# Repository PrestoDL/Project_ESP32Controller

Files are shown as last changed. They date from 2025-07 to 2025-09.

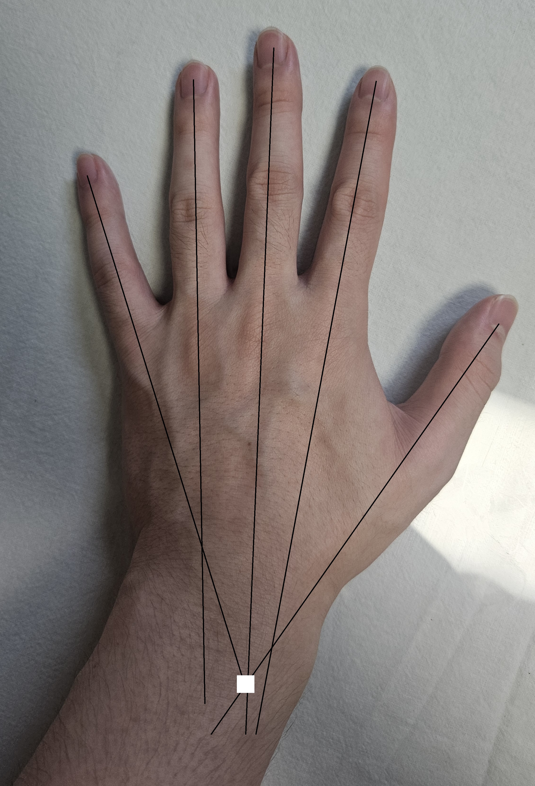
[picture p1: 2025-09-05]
modeling/hand.jpg

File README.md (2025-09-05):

# Project_ESP32Controller
Project about ESP32 motion controller with ESP-IDF. For IoT properties, additional function will be installed.

Demo test is about controlling light with http request by simple motion.

Demo test in my channel :

https://youtube.com/shorts/M0vYTvH4euw?si=jk3dXooK5vRalX_q

KakaoTalk_20250905_214945616

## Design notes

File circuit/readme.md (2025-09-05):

PCB circuit design on KiCad.

circuitSCH

circuitPCB

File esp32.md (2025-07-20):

# FreeRTOS

## // Task

메인 루프의 일종이라고 보면 될 것

## // Wi-Fi

대표적으로 두가지 모드가 있다

액세스 포인트(AP) : 다른 장치들이 연결할 수 있는, 일종의 공유기로 보드를 사용

스테이션(STA) : 보드를 다른 네트워크에 연결하여 인터넷 액세스 등 가능

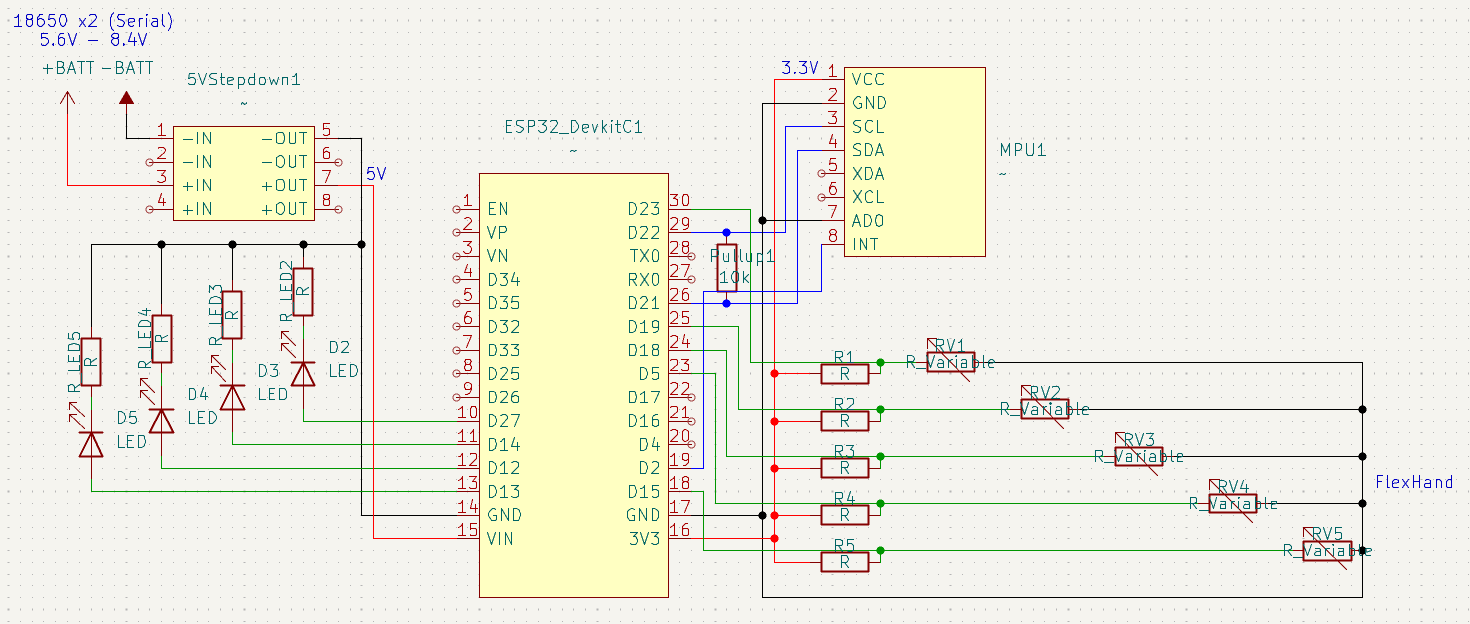
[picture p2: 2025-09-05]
circuit/circuitSCH.png

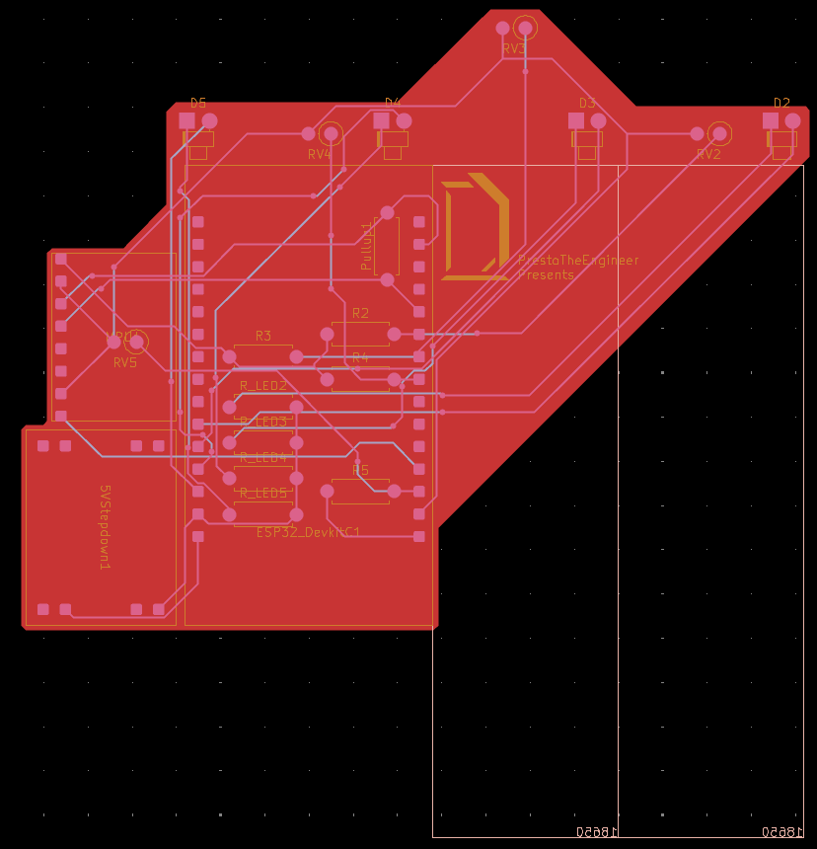
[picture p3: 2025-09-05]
circuit/circuitPCB.png

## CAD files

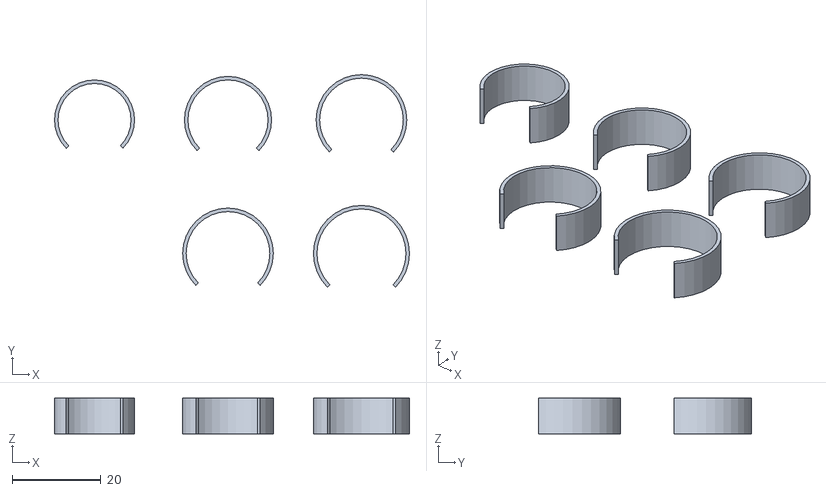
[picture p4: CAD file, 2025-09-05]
modeling/fingTemp.stl
79.8 x 47.8 x 8.00

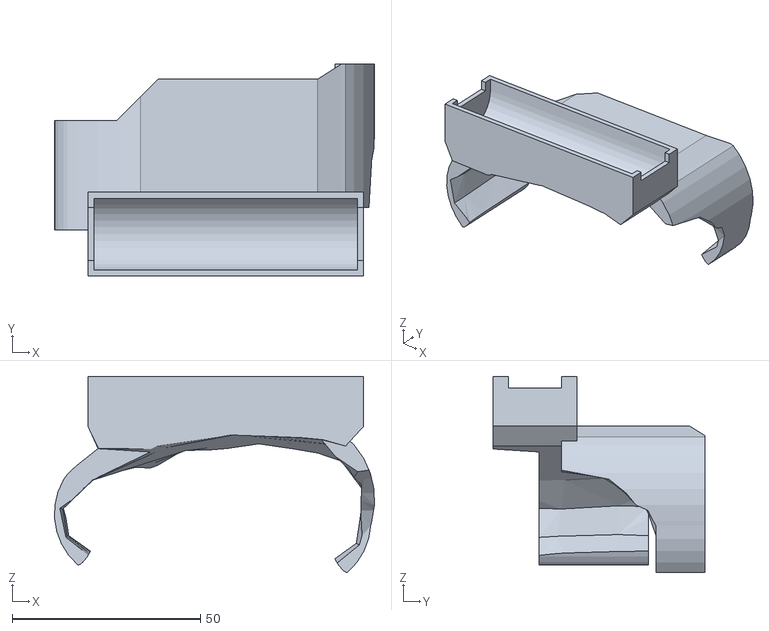
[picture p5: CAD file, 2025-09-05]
modeling/wristTemp.stl
84.9 x 56.2 x 52.0

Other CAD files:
modeling/WristController.blend

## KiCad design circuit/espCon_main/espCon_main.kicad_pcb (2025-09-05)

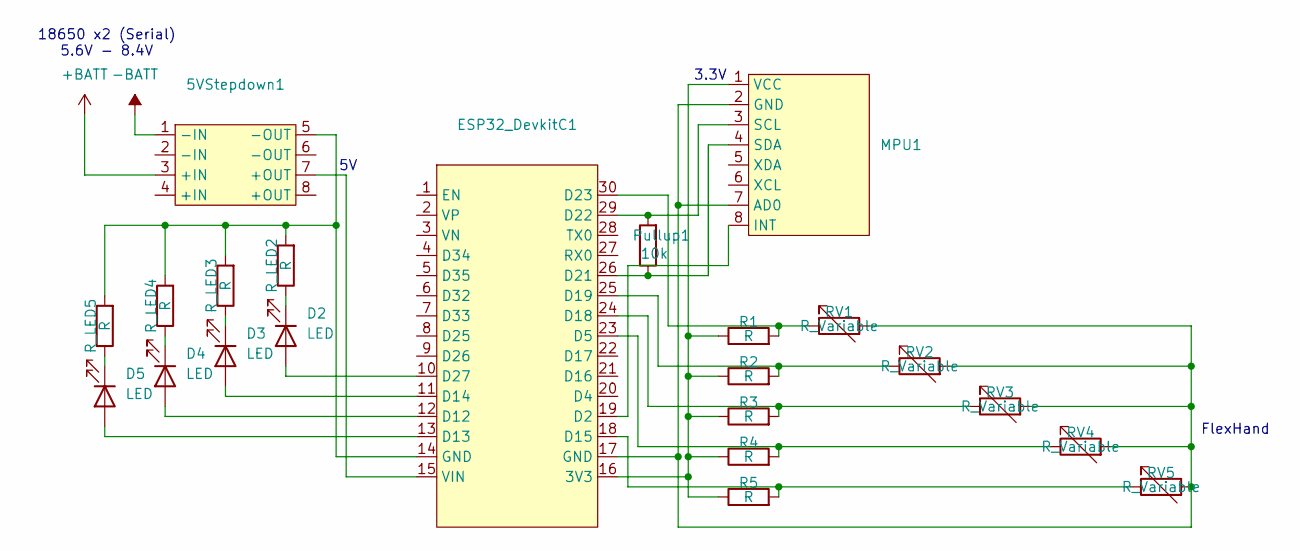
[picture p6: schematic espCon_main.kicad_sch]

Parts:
5VStepdown1: 5VStepdown
D2, D3, D4, D5: LED; LED_D1.8mm_W1.8mm_H2.4mm_Horizontal_O1.27mm_Z1.6mm
ESP32_DevkitC1: ESP32_DevkitC
MPU1: GY-521
Pullup1: 10k; R_Axial_DIN0207_L6.3mm_D2.5mm_P2.54mm_Vertical
R1, R2, R3, R4, R5: R; R_Axial_DIN0207_L6.3mm_D2.5mm_P2.54mm_Vertical
RV1, RV2, RV3, RV4, RV5: R_Variable; R_Axial_DIN0207_L6.3mm_D2.5mm_P2.54mm_Vertical
R_LED2, R_LED3, R_LED4, R_LED5: R; R_Axial_DIN0207_L6.3mm_D2.5mm_P2.54mm_Vertical

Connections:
+BATT: 5VStepdown1.3 (+IN)
-BATT: 5VStepdown1.1 (-IN)
unnamed: 5VStepdown1.5 (-OUT), ESP32_DevkitC1.14 (GND), R_LED2.2, R_LED3.2, R_LED4.2, R_LED5.2
unnamed: D2.2 (A), ESP32_DevkitC1.10 (D27)
unnamed: D2.1 (K), R_LED2.1
unnamed: D3.2 (A), ESP32_DevkitC1.11 (D14)
unnamed: D3.1 (K), R_LED3.1
unnamed: D4.2 (A), ESP32_DevkitC1.12 (D12)
unnamed: D4.1 (K), R_LED4.1
unnamed: D5.2 (A), ESP32_DevkitC1.13 (D13)
unnamed: D5.1 (K), R_LED5.1
unnamed: ESP32_DevkitC1.16 (3V3), MPU1.1 (VCC), R1.1, R2.1, R3.1, R4.1, R5.1
unnamed: ESP32_DevkitC1.19 (D2), MPU1.8 (INT)
unnamed: ESP32_DevkitC1.23 (D5), R4.2, RV4.1
unnamed: ESP32_DevkitC1.18 (D15), R5.2, RV5.1
unnamed: ESP32_DevkitC1.24 (D18), R3.2, RV3.1
unnamed: ESP32_DevkitC1.25 (D19), R2.2, RV2.1
unnamed: ESP32_DevkitC1.26 (D21), MPU1.4 (SDA), Pullup1.1
unnamed: ESP32_DevkitC1.29 (D22), MPU1.3 (SCL), Pullup1.2
unnamed: ESP32_DevkitC1.30 (D23), R1.2, RV1.1
unnamed: 5VStepdown1.7 (+OUT), ESP32_DevkitC1.15 (VIN)
unnamed: ESP32_DevkitC1.17 (GND), MPU1.2 (GND), MPU1.7 (AD0), RV1.2, RV2.2, RV3.2, RV4.2, RV5.2

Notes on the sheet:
18650 x2 (Serial) 5.6V - 8.4V
3.3V
FlexHand

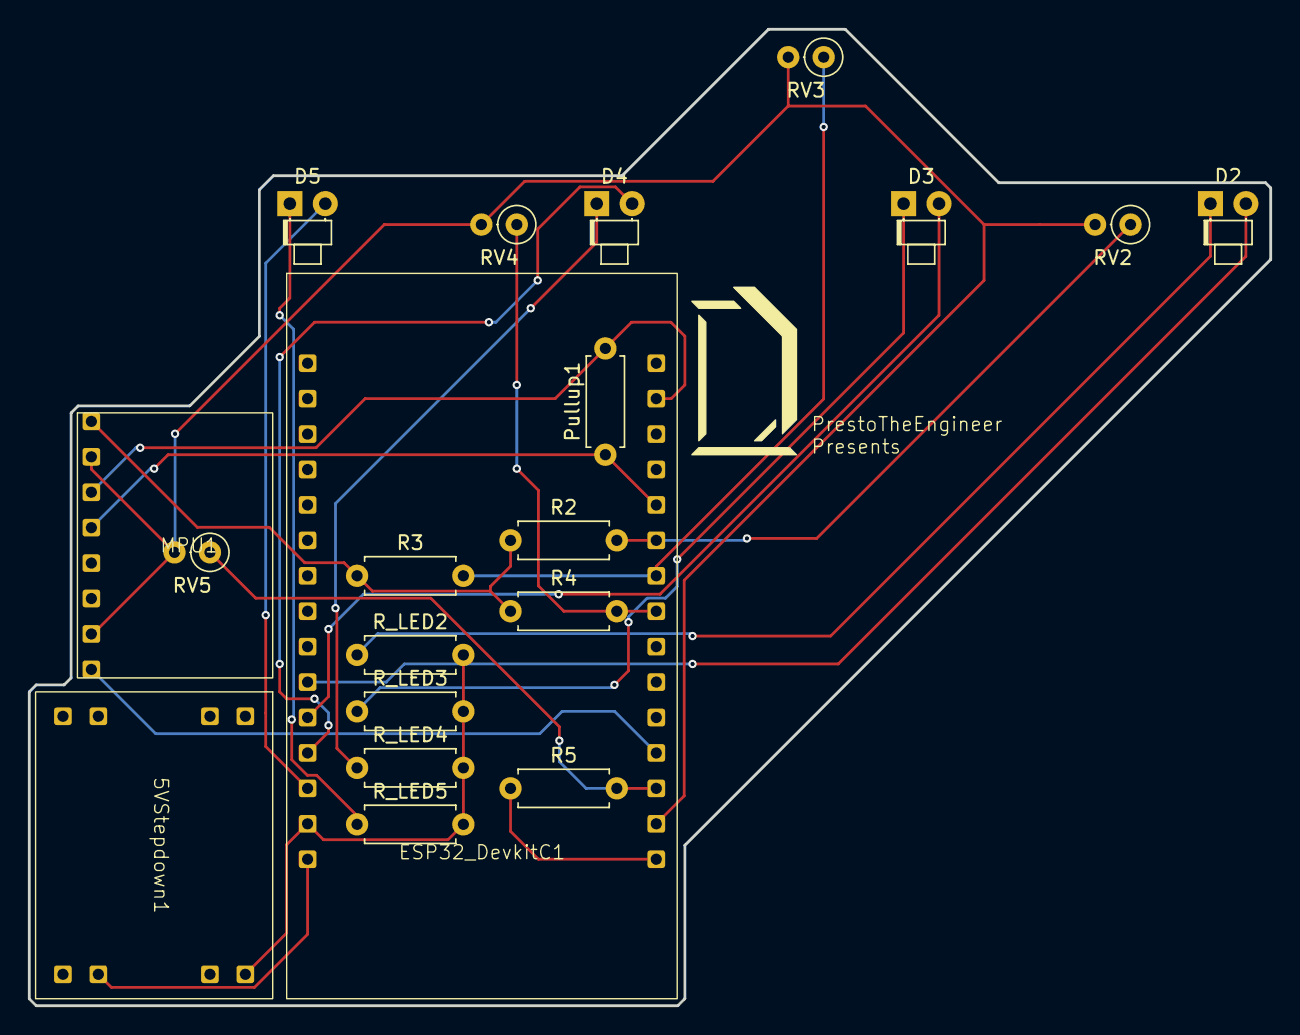
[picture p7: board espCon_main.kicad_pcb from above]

Board: 2 copper layers, 89.0 x 70.0 mm, 20 parts (0 on the bottom side), 19 nets.

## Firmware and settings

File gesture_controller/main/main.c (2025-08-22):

#include <stdio.h>
#include "freertos/FreeRTOS.h"
#include "freertos/task.h"
#include "freertos/semphr.h"
#include "esp_log.h"
#include "esp_wifi.h"
#include "nvs_flash.h"
#include "esp_netif.h"
#include "driver/gpio.h"
#include "driver/i2c_master.h"
#include "esp_http_client.h"

static const char *TAG = "GESTURE_CONTROLLER";

#define WIFI_SSID       "..."
#define WIFI_PASSWORD   "..."
#define RPI_IP          "..."
#define RPI_PORT        "..."

#define WIFI_LED                    GPIO_NUM_2
#define I2C_MASTER_SCL_IO           GPIO_NUM_22
#define I2C_MASTER_SDA_IO           GPIO_NUM_21
#define I2C_MASTER_FREQ_HZ          400000
#define MPU6050_DEVICE_ADDRESS      0x68
#define MPU6050_INT_PIN             GPIO_NUM_4
#define FLIP_THRESHOLD_G            0.5f
#define MOT_THR                     1

#define MPU6050_ACCEL_XOUT_H        0x3B
#define MPU6050_CONFIG              0x1A
#define MPU6050_ACCEL_CONFIG        0x1C
#define MPU6050_MOT_THR_REG         0x1F
#define MPU6050_MOT_DUR_REG         0x20
#define MPU6050_INT_PIN_CFG         0x37
#define MPU6050_INT_ENABLE          0x38
#define MPU6050_INT_STATUS          0x3A
#define MPU6050_PWR_MGMT_1          0x6B
#define MPU6050_PWR_MGMT_2          0x6C
#define MPU6050_MOT_DETECT_INT_BIT  (1 << 6)

#define DEBOUNCE_DELAY_MS 1500
static uint32_t last_trigger_time = 0;

static i2c_master_bus_handle_t bus_handle;
static i2c_master_dev_handle_t dev_handle;
static SemaphoreHandle_t motion_sem;
static bool is_wifi_connected = false;
static bool status_light = false;

esp_err_t nvs_init(void) {
    esp_err_t ret = nvs_flash_init();
    if (ret == ESP_ERR_NVS_NO_FREE_PAGES || ret == ESP_ERR_NVS_NEW_VERSION_FOUND) {
        ESP_ERROR_CHECK(nvs_flash_erase());
        ret = nvs_flash_init();
    }

    return ret;
}

esp_err_t gpio_init(void) {
    gpio_config_t io_conf_int = {
        .pin_bit_mask = (1ULL << MPU6050_INT_PIN),
        .mode = GPIO_MODE_INPUT,
        .intr_type = GPIO_INTR_POSEDGE
    };
    ESP_ERROR_CHECK(gpio_config(&io_conf_int));

    gpio_config_t io_conf_led = {
        .pin_bit_mask = (1ULL << WIFI_LED),
        .mode = GPIO_MODE_OUTPUT,
    };

    return gpio_config(&io_conf_led);
}

esp_err_t i2c_bus_init(void) {
    i2c_master_bus_config_t i2c_bus_config = {
        .i2c_port = I2C_NUM_0,
        .sda_io_num = I2C_MASTER_SDA_IO,
        .scl_io_num = I2C_MASTER_SCL_IO,
        .clk_source = I2C_CLK_SRC_DEFAULT,
        .glitch_ignore_cnt = 7,
        .flags.enable_internal_pullup = true,
    };

    return i2c_new_master_bus(&i2c_bus_config, &bus_handle);
}

esp_err_t i2c_device_init(void) {
    i2c_device_config_t dev_cfg = {
        .dev_addr_length = I2C_ADDR_BIT_LEN_7,
        .device_address = MPU6050_DEVICE_ADDRESS,
        .scl_speed_hz = I2C_MASTER_FREQ_HZ,
    };

    return i2c_master_bus_add_device(bus_handle, &dev_cfg, &dev_handle);
}

void send_light_command(const char* state)
{
    if (!is_wifi_connected) {
        ESP_LOGE(TAG, "Wi-Fi is not Connected.");
        return;
    }

    char path_buffer[32];
    sprintf(path_buffer, "/light/%s", state);

    esp_http_client_config_t config = {
        .host = RPI_IP,
        .port = RPI_PORT,
        .path = path_buffer,
        .transport_type = HTTP_TRANSPORT_OVER_TCP,
        .timeout_ms = 10000,
    };
    esp_http_client_handle_t client = esp_http_client_init(&config);
    esp_err_t err = esp_http_client_perform(client);

    if (err == ESP_OK) {
        ESP_LOGI(TAG, "HTTP GET Request Success (%s), Code = %d", state, esp_http_client_get_status_code(client));
    } else {
        ESP_LOGE(TAG, "HTTP GET Request Failed : %s", esp_err_to_name(err));
    }

    esp_http_client_cleanup(client);
}

esp_err_t mpu6050_init(void)
{
    esp_err_t ret;
    uint8_t cmd_buffer[2];

    cmd_buffer[0] = MPU6050_PWR_MGMT_1; cmd_buffer[1] = 0x80;
    ret = i2c_master_transmit(dev_handle, cmd_buffer, 2, -1); vTaskDelay(pdMS_TO_TICKS(100));
    cmd_buffer[0] = MPU6050_PWR_MGMT_1; cmd_buffer[1] = 0x01;
    ret = i2c_master_transmit(dev_handle, cmd_buffer, 2, -1);
    cmd_buffer[0] = MPU6050_PWR_MGMT_2; cmd_buffer[1] = 0x00;
    ret = i2c_master_transmit(dev_handle, cmd_buffer, 2, -1); vTaskDelay(pdMS_TO_TICKS(100));
    cmd_buffer[0] = MPU6050_CONFIG; cmd_buffer[1] = 0x01;
    ret = i2c_master_transmit(dev_handle, cmd_buffer, 2, -1);
    cmd_buffer[0] = MPU6050_ACCEL_CONFIG; cmd_buffer[1] = 0x08;
    ret = i2c_master_transmit(dev_handle, cmd_buffer, 2, -1);
    cmd_buffer[0] = MPU6050_MOT_THR_REG; cmd_buffer[1] = MOT_THR;
    ret = i2c_master_transmit(dev_handle, cmd_buffer, 2, -1);
    cmd_buffer[0] = MPU6050_MOT_DUR_REG; cmd_buffer[1] = 1;
    ret = i2c_master_transmit(dev_handle, cmd_buffer, 2, -1);
    cmd_buffer[0] = MPU6050_INT_PIN_CFG; cmd_buffer[1] = 0x20;
    ret = i2c_master_transmit(dev_handle, cmd_buffer, 2, -1);
    cmd_buffer[0] = MPU6050_INT_ENABLE; cmd_buffer[1] = MPU6050_MOT_DETECT_INT_BIT;
    ret = i2c_master_transmit(dev_handle, cmd_buffer, 2, -1);
    cmd_buffer[0] = MPU6050_PWR_MGMT_1; cmd_buffer[1] = 0x21;
    ret = i2c_master_transmit(dev_handle, cmd_buffer, 2, -1);
    cmd_buffer[0] = MPU6050_PWR_MGMT_2; cmd_buffer[1] = 0xC7;
    ret = i2c_master_transmit(dev_handle, cmd_buffer, 2, -1);

    return ret;
}

static void IRAM_ATTR gpio_isr_handler(void *arg) {
    xSemaphoreGiveFromISR(motion_sem, NULL);
}

static void gesture_detect_task(void *arg) {
    uint8_t int_status;
    uint8_t acce_buffer[6];
    const float acce_sensitivity = 8192.0f;

    while (1) {
        if (xSemaphoreTake(motion_sem, portMAX_DELAY) == pdTRUE) {
            uint32_t current_time = esp_log_timestamp();
            if (current_time - last_trigger_time < DEBOUNCE_DELAY_MS) {
                ESP_LOGW(TAG, "Signal cooldown : %lu ms left)", DEBOUNCE_DELAY_MS - (current_time - last_trigger_time));
                i2c_master_transmit_receive(dev_handle, &((uint8_t){MPU6050_INT_STATUS}), 1, &int_status, 1, -1);
                continue;
            }
            ESP_LOGI(TAG, "Motion Interrupt Received by Task!");

            i2c_master_transmit_receive(dev_handle, &((uint8_t){MPU6050_INT_STATUS}), 1, &int_status, 1, -1);
            
            if (int_status & MPU6050_MOT_DETECT_INT_BIT) {
                i2c_master_transmit_receive(dev_handle, &((uint8_t){MPU6050_ACCEL_XOUT_H}), 1, acce_buffer, 6, -1);
                int16_t raw_acce_z = (int16_t)((acce_buffer[4] << 8) | acce_buffer[5]);
                float acce_z = raw_acce_z / acce_sensitivity;

                bool command_sent = false;
                if (acce_z > FLIP_THRESHOLD_G && status_light == false) {
                    ESP_LOGW(TAG, "== Palm UP ==> LED ON");
                    send_light_command("on");
                    command_sent = true;
                    status_light = true;
                } else if (acce_z < -FLIP_THRESHOLD_G && status_light == true) {
                    ESP_LOGW(TAG, "== Palm DOWN ==> LED OFF");
                    send_light_command("off");
                    command_sent = true;
                    status_light = false;
                }

                if(command_sent) {
                    last_trigger_time = esp_log_timestamp();
                }
            }
        }
    }
}

static void wifi_event_handler(void* arg, esp_event_base_t event_base, int32_t event_id, void* event_data) {
    if (event_base == WIFI_EVENT && event_id == WIFI_EVENT_STA_START) {
        esp_wifi_connect();
    } else if (event_base == WIFI_EVENT && event_id == WIFI_EVENT_STA_DISCONNECTED) {
        is_wifi_connected = false;
        ESP_LOGI(TAG, "Wi-Fi Disconnected. Retry...");
        gpio_set_level(WIFI_LED, 0);
        esp_wifi_connect();
    } else if (event_base == IP_EVENT && event_id == IP_EVENT_STA_GOT_IP) {
        ip_event_got_ip_t* event = (ip_event_got_ip_t*) event_data;
        ESP_LOGI(TAG, "Wi-Fi Connected! IP: " IPSTR, IP2STR(&event->ip_info.ip));
        gpio_set_level(WIFI_LED, 1);
        is_wifi_connected = true;
    }
}

esp_err_t wifi_sta_init(void) {
    ESP_ERROR_CHECK(esp_netif_init());
    ESP_ERROR_CHECK(esp_event_loop_create_default());
    esp_netif_create_default_wifi_sta();
    wifi_init_config_t cfg = WIFI_INIT_CONFIG_DEFAULT();
    ESP_ERROR_CHECK(esp_wifi_init(&cfg));
    esp_event_handler_instance_t instance_any_id;
    esp_event_handler_instance_t instance_got_ip;
    ESP_ERROR_CHECK(esp_event_handler_instance_register(WIFI_EVENT, ESP_EVENT_ANY_ID, &wifi_event_handler, NULL, &instance_any_id));
    ESP_ERROR_CHECK(esp_event_handler_instance_register(IP_EVENT, IP_EVENT_STA_GOT_IP, &wifi_event_handler, NULL, &instance_got_ip));
    wifi_config_t wifi_config = { .sta = { .ssid = WIFI_SSID, .password = WIFI_PASSWORD, }, };
    ESP_ERROR_CHECK(esp_wifi_set_mode(WIFI_MODE_STA) );
    ESP_ERROR_CHECK(esp_wifi_set_config(WIFI_IF_STA, &wifi_config) );
    return esp_wifi_start();
}

void app_main(void) {
    motion_sem = xSemaphoreCreateBinary();
    ESP_ERROR_CHECK(nvs_init());

    ESP_ERROR_CHECK(i2c_bus_init());
    ESP_ERROR_CHECK(i2c_device_init());
    ESP_ERROR_CHECK(gpio_init());
    ESP_ERROR_CHECK(mpu6050_init());

    ESP_ERROR_CHECK(gpio_install_isr_service(0));

    ESP_ERROR_CHECK(gpio_isr_handler_add(MPU6050_INT_PIN, gpio_isr_handler, NULL));
    xTaskCreate(gesture_detect_task, "gesture_detect", 8192, NULL, 5, NULL);

    ESP_ERROR_CHECK(wifi_sta_init());

    ESP_LOGI(TAG, "Initialization complete. Waiting for gestures...");
}

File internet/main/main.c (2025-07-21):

#include "freertos/FreeRTOS.h"
#include "freertos/task.h"
#include "esp_wifi.h"
#include "esp_event.h"
#include "nvs_flash.h"
#include "esp_log.h"

#define WIFI_SSID      ""
#define WIFI_PASS      ""

static const char *TAG = "wifi_sta";

void wifi_event_handler(void* arg, esp_event_base_t event_base, int32_t event_id, void* event_data) {
    if (event_base == WIFI_EVENT && event_id == WIFI_EVENT_STA_START) {
        esp_wifi_connect();
    } else if (event_base == WIFI_EVENT && event_id == WIFI_EVENT_STA_DISCONNECTED) {
        ESP_LOGI(TAG, "Retrying to connect to the AP");
        esp_wifi_connect();
    } else if (event_base == IP_EVENT && event_id == IP_EVENT_STA_GOT_IP) {
        ip_event_got_ip_t* event = (ip_event_got_ip_t*) event_data;
        char buff[64];
        ESP_LOGI(TAG, "Got IP: %s", esp_ip4addr_ntoa(&event->ip_info.ip, buff, 64));
    }
}

void wifi_init_sta(void) {
    ESP_ERROR_CHECK(nvs_flash_init());
    ESP_ERROR_CHECK(esp_netif_init());
    ESP_ERROR_CHECK(esp_event_loop_create_default());

    esp_netif_create_default_wifi_sta();

    wifi_init_config_t cfg = WIFI_INIT_CONFIG_DEFAULT();
    ESP_ERROR_CHECK(esp_wifi_init(&cfg));

    esp_event_handler_instance_t instance_any_id;
    esp_event_handler_instance_t instance_got_ip;
    ESP_ERROR_CHECK(esp_event_handler_instance_register(WIFI_EVENT,
                                                        ESP_EVENT_ANY_ID,
                                                        &wifi_event_handler,
                                                        NULL,
                                                        &instance_any_id));
    ESP_ERROR_CHECK(esp_event_handler_instance_register(IP_EVENT,
                                                        IP_EVENT_STA_GOT_IP,
                                                        &wifi_event_handler,
                                                        NULL,
                                                        &instance_got_ip));

    wifi_config_t wifi_config = {
        .sta = {
            .ssid = WIFI_SSID,
            .password = WIFI_PASS,
        },
    };
    ESP_ERROR_CHECK(esp_wifi_set_mode(WIFI_MODE_STA));
    ESP_ERROR_CHECK(esp_wifi_set_config(ESP_IF_WIFI_STA, &wifi_config));
    ESP_ERROR_CHECK(esp_wifi_start());
}

void app_main(void) {
    wifi_init_sta();
}

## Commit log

2025-08-26 Update README.md
    uploaded prototype
2025-09-05 Added circuit file and modeling file
    [WristController.blend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]
